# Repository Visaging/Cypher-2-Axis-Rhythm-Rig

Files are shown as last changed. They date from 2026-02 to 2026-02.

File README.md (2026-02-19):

# Cypher - 2 Axis Rhythm Rig
# TBA






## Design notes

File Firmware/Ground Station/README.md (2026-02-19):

# Breakdown Of the Firmware
- I wrote a custom protocol that sends a 13-byte package to the FC in the same format as designed in the firmware for the FC.
	- Joystick Axis: `Throttle`, `Yaw`, `Pitch`, `Roll`
	- Knobs: Direct Control for Gimbal Pitch and Roll
	- Buttons: Sends `CAM UP`, `CAM DOWN`, `ARM` and `DISARM` in a bitmask byte.
- I did not want to complicate things by getting the telemetry back from the drone itself instead, it sends the telemetry to the Raspberry Pi via `UART5`. The Raspberry Pi streams this telemetry back along with the video feed.
	- The ground station itself is set to blind transmission for now.
- Instead of displaying `BATTERY: 3.5V` on the OLED, I added some basic maths to map the voltage into a clean percentage based system. Now the OLED displays `BATTERY: 78%`.
- Although the UI for the OLED is pretty basic, it displays:
	- Battery percentage on the top.
	- Drone arm status: `ARMED`/`DISARMED` in the middle.
	- Raw stick values: `Throttle:`, `Roll:` and `Pitch:` on the bottom.

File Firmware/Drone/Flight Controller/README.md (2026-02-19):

# Breakdown:
- Since I'm using `DRV8313` as the motor drivers for the gimbal motors, I wrote a custom Sinusoidal PWM generator to drive the motors.
	- I also bumped the timer frequency to `20KHz` so the motors don't make a band of their own.
- Since I added a disarm button on the Ground Station, I added a safety mechanism to prevent accidental button presses and mid-air shutdowns unless absolutely necessary.
	- The drone disarms only when the button is pressed twice.
- Since I'm running a 6S battery structure for better efficiency and flight time, but my motors are rated for 4S batteries, I implemented a hardcoded firmware limit. It limits the motors to 66%.
	- This makes the drone work like it would when it's connected to a 4S battery structure.
- In the last firmware I wrote, I did not account for the buttons and knobs on the ground station. I expanded the 9-byte packet to a 13-byte package.
	- It now accommodates the knobs for direct control of the gimbal pitch and roll.
	- I added firmware for the buttons that handle `Camera Down`, `Camera Up`, `Arm`, and `Disarm`.
- I also did not set up the stabilisation for the gimbal in the last firmware. Now, the gimbal isn't just on manual control, it stabilises the camera.
	- I updated the math to subtract the drone's IMU angle from the target angle, resulting in active stabilisation even if the drone moves fast.

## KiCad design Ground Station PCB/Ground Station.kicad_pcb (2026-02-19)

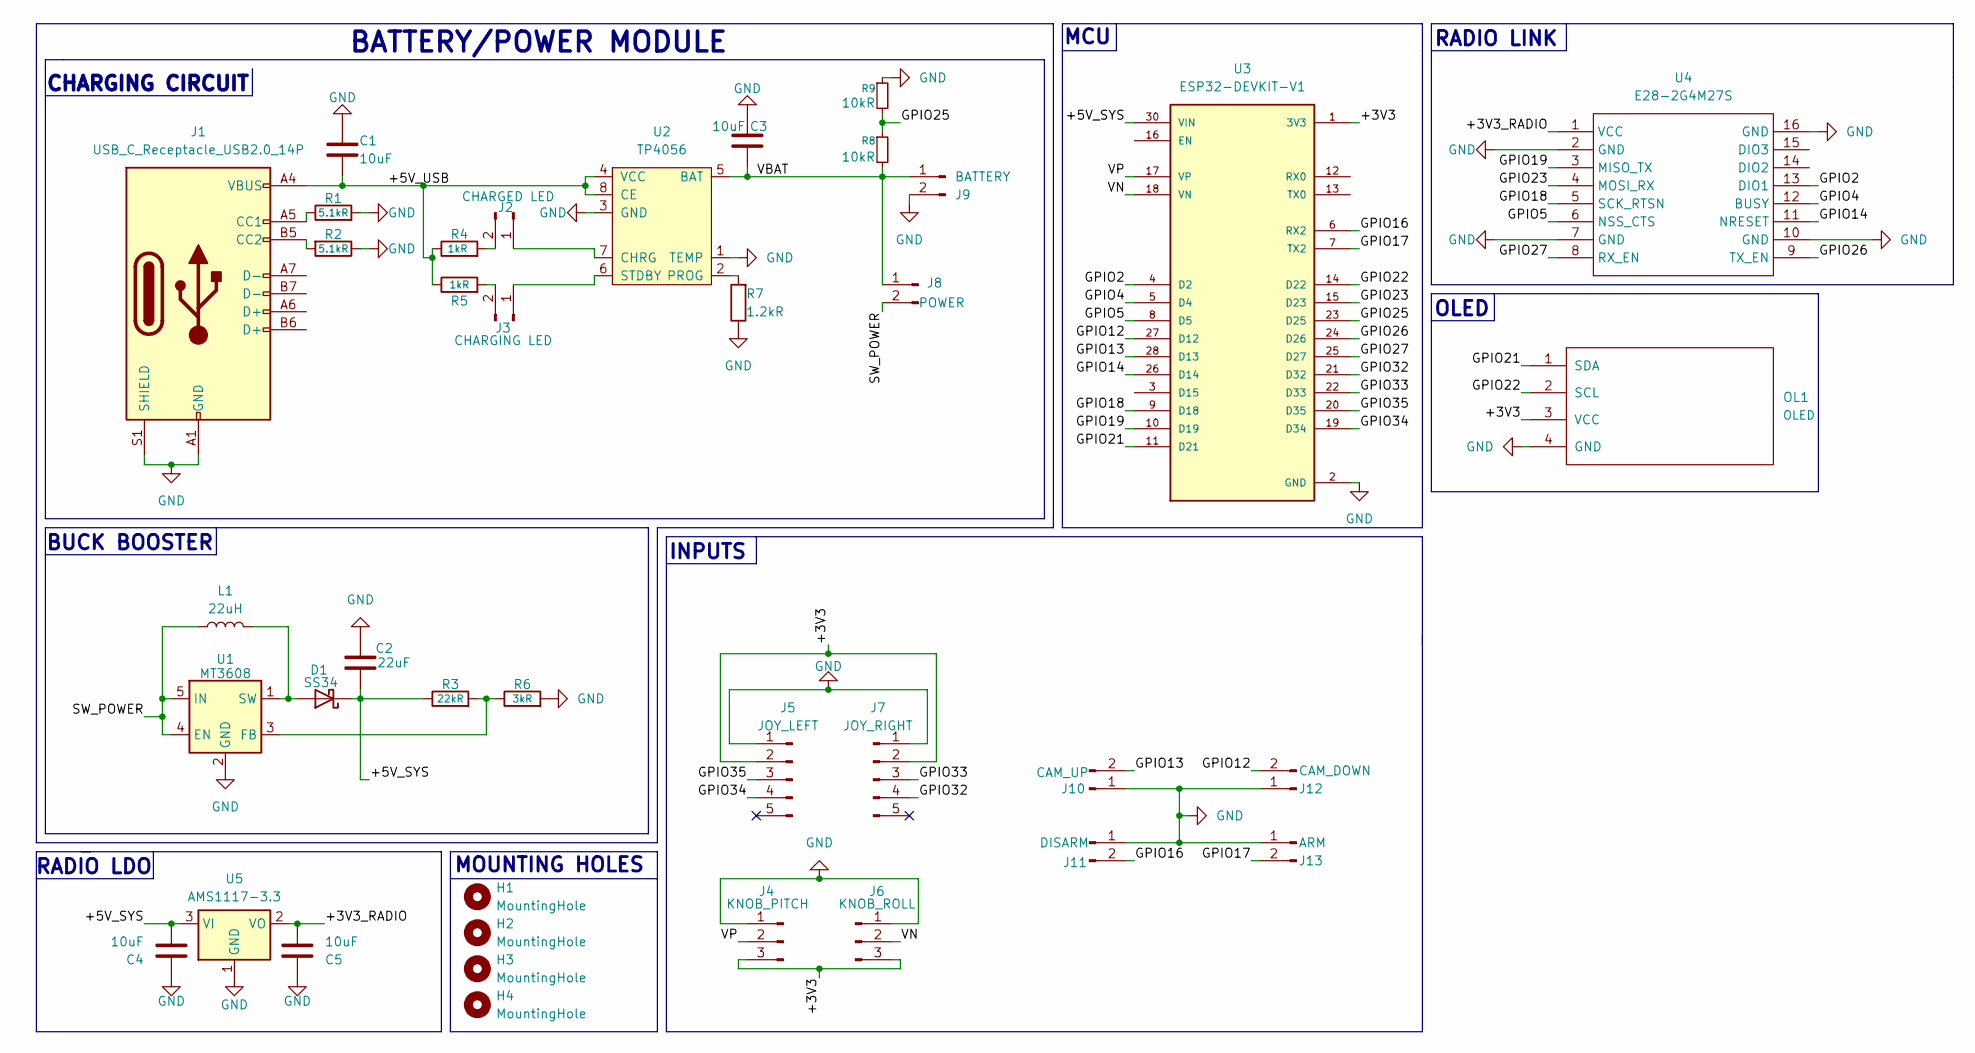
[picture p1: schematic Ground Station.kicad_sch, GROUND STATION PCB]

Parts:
C1, C4, C5: 10uF; C_0805_2012Metric
C2: 22uF; C_0805_2012Metric
C3: 10uF; CP_Radial_D5.0mm_P2.50mm
D1: SS34; D_SMA
H1, H2, H3, H4: MountingHole; MountingHole_3.2mm_M3
J1: USB_C_Receptacle_USB2.0_14P; USB_C_Receptacle_HRO_TYPE-C-31-M-12
J2: CHARGED LED; SolderWire-0.1sqmm_1x02_P3.6mm_D0.4mm_OD1mm
J3: CHARGING LED; SolderWire-0.1sqmm_1x02_P3.6mm_D0.4mm_OD1mm
J4: KNOB_PITCH; PinHeader_1x03_P2.54mm_Vertical
J5: JOY_LEFT; PinHeader_1x05_P2.54mm_Vertical
J6: KNOB_ROLL; PinHeader_1x03_P2.54mm_Vertical
J7: JOY_RIGHT; PinHeader_1x05_P2.54mm_Vertical
J8: POWER; PinHeader_1x02_P2.54mm_Vertical
J9: BATTERY; PinHeader_1x02_P2.54mm_Vertical
J10: CAM_UP; SolderWire-0.1sqmm_1x02_P3.6mm_D0.4mm_OD1mm
J11: DISARM; SolderWire-0.1sqmm_1x02_P3.6mm_D0.4mm_OD1mm
J12: CAM_DOWN; SolderWire-0.1sqmm_1x02_P3.6mm_D0.4mm_OD1mm
J13: ARM; SolderWire-0.1sqmm_1x02_P3.6mm_D0.4mm_OD1mm
L1: 22uH; L_Bourns-SRN6028
OL1: OLED; PinHeader_1x04_P2.54mm_Vertical
R1, R2: 5.1kR; R_0805_2012Metric
R3: 22kR; R_0805_2012Metric
R4, R5: 1kR; R_0805_2012Metric
R6: 3kR; R_0805_2012Metric
R7: 1.2kR; R_0805_2012Metric
R8, R9: 10kR; R_0805_2012Metric
U1: MT3608; SOP-8-1EP_4.57x4.57mm_P1.27mm_EP4.57x4.45mm
U2: TP4056; SOIC-8-1EP_3.9x4.9mm_P1.27mm_EP2.29x3mm; LCSC C16581
U3: ESP32-DEVKIT-V1; MODULE_ESP32_DEVKIT_V1; PARTREV N/A
U4: E28-2G4M27S; WIRELM-SMD_E28-2G4M2XS; Manufacturer Part E28-2G4M27S; LCSC Part Name E28-2G4M27S
U5: AMS1117-3.3; SOT-223-3_TabPin2

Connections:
/+3V3: J4.3, J5.2, J6.3, J7.2, OL1.3 (VCC), U3.1 (3V3)
/+3V3_RADIO: C5.2, U4.1 (VCC), U5.2 (VO)
/+5V_SYS: C2.2, C4.2, D1.1 (K), R3.1, U3.30 (VIN), U5.3 (VI)
/+5V_USB: C1.2, J1.A4 (VBUS), J1.A9 (VBUS), J1.B4 (VBUS), J1.B9 (VBUS), R4.1, R5.1, U2.4 (VCC), U2.8 (CE)
/GPIO2: U3.4 (D2), U4.13 (DIO1)
/GPIO4: U3.5 (D4), U4.12 (BUSY)
/GPIO5: U3.8 (D5), U4.6 (NSS_CTS)
/GPIO12: J12.2, U3.27 (D12)
/GPIO13: J10.2, U3.28 (D13)
/GPIO14: U3.26 (D14), U4.11 (NRESET)
/GPIO16: J11.2, U3.6 (RX2)
/GPIO17: J13.2, U3.7 (TX2)
/GPIO18: U3.9 (D18), U4.5 (SCK_RTSN)
/GPIO19: U3.10 (D19), U4.3 (MISO_TX)
/GPIO21: OL1.1 (SDA), U3.11 (D21)
/GPIO22: OL1.2 (SCL), U3.14 (D22)
/GPIO23: U3.15 (D23), U4.4 (MOSI_RX)
/GPIO25: R8.1, R9.2, U3.23 (D25)
/GPIO26: U3.24 (D26), U4.9 (TX_EN)
/GPIO27: U3.25 (D27), U4.8 (RX_EN)
/GPIO32: J7.4, U3.21 (D32)
/GPIO33: J7.3, U3.22 (D33)
/GPIO34: J5.4, U3.19 (D34)
/GPIO35: J5.3, U3.20 (D35)
/SW_POWER: J8.2, L1.1, U1.4 (EN), U1.5 (IN)
/VBAT: C3.2, J8.1, J9.1, R8.2, U2.5 (BAT)
/VN: J6.2, U3.18 (VN)
/VP: J4.2, U3.17 (VP)
GND: C1.1, C2.1, C3.1, C4.1, C5.1, J1.A1 (GND), J1.A12 (GND), J1.B1 (GND), J1.B12 (GND), J1.S1 (SHIELD), J4.1, J5.1, J6.1, J7.1, J9.2, J10.1, J11.1, J12.1, J13.1, OL1.4 (GND), R1.2, R2.1, R6.2, R7.1, R9.1, U1.2 (GND), U2.1 (TEMP), U2.3 (GND), U3.2 (GND), U3.29 (GND), U4.2 (GND), U4.7 (GND), U4.10 (GND), U4.16 (GND), U5.1 (GND)
unnamed: D1.2 (A), L1.2, U1.1 (SW)
unnamed: J1.A5 (CC1), R1.1
unnamed: J1.B5 (CC2), R2.2
unnamed: J2.1, U2.7 (CHRG)
unnamed: J2.2, R4.2
unnamed: J3.1, U2.6 (STDBY)
unnamed: J3.2, R5.2
unnamed: R3.2, R6.1, U1.3 (FB)
unnamed: R7.2, U2.2 (PROG)

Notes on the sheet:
MCU
OLED
INPUTS
CHARGING CIRCUIT
MOUNTING HOLES
RADIO LINK
BATTERY/POWER MODULE
BUCK BOOSTER
RADIO LDO

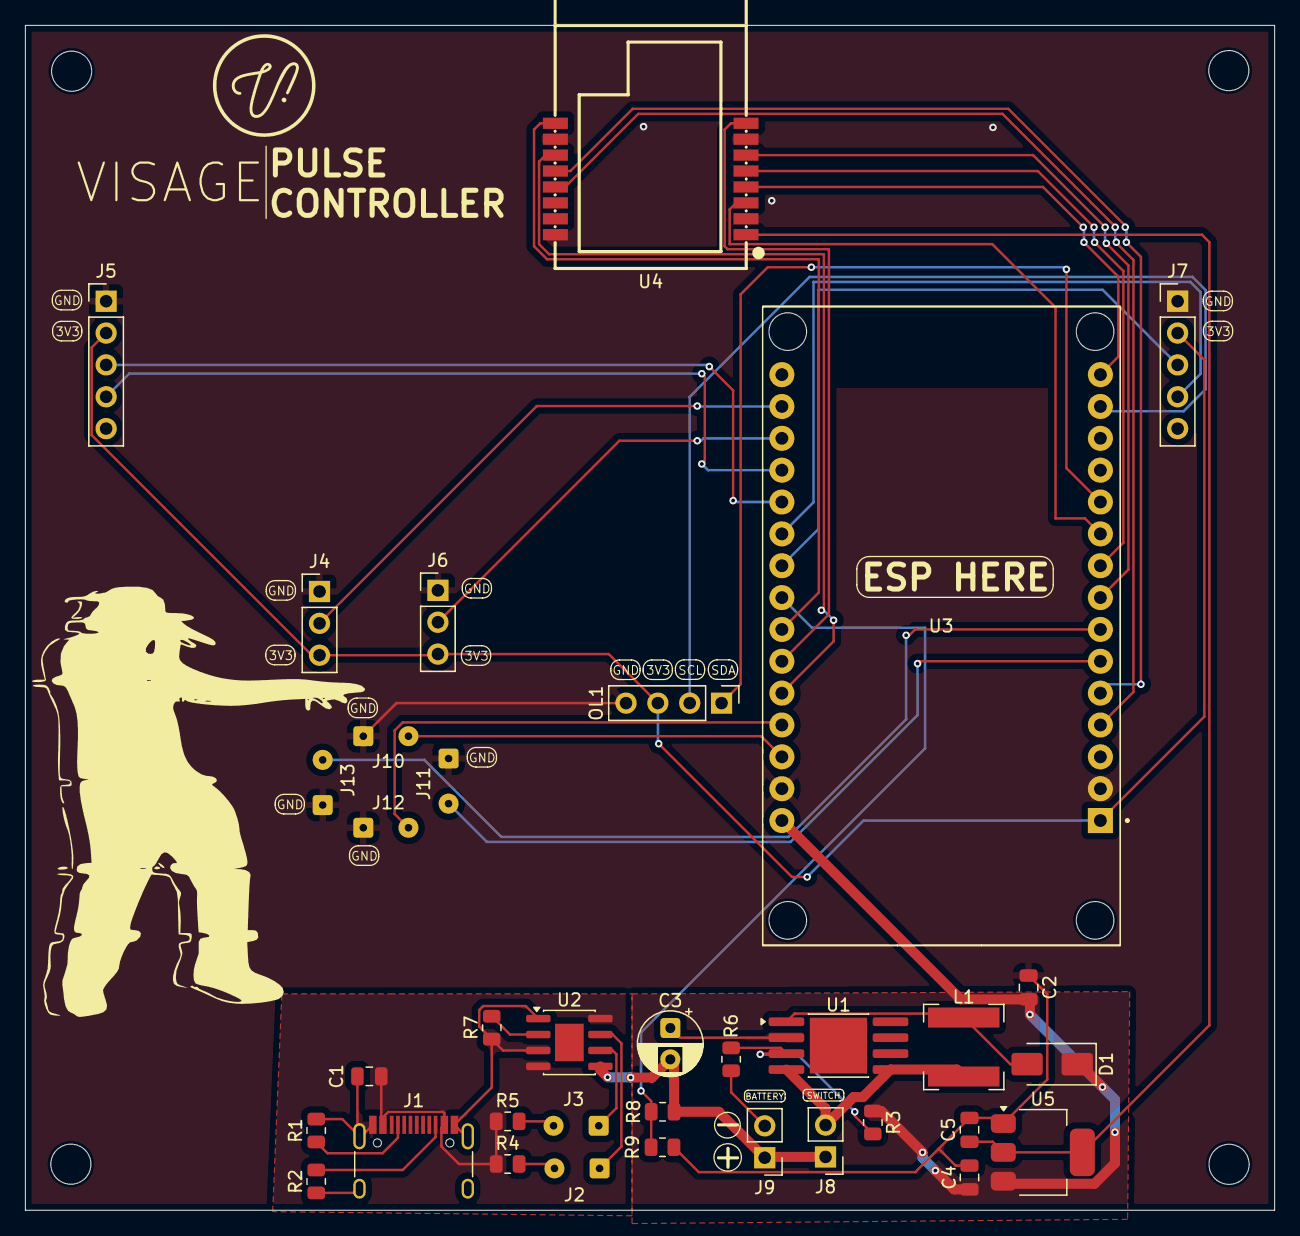
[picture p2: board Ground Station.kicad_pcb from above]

Board: 2 copper layers, 99.6 x 94.5 mm, 39 parts (0 on the bottom side), 38 nets.

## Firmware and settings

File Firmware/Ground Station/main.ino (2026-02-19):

#include <SPI.h>
#include <Wire.h>
#include <Adafruit_GFX.h>
#include <Adafruit_SSD1306.h>
#include <SX128XLT.h>

// ================================================================
// --- 1. PIN DEFINITIONS (MATCHING YOUR SCHEMATIC) ---
// ================================================================

// Analog Inputs (Joysticks + Knobs)
#define PIN_JOY_YAW     35
#define PIN_JOY_THR     34
#define PIN_JOY_ROLL    33
#define PIN_JOY_PITCH   32
#define PIN_KNOB_PITCH  36 // VP
#define PIN_KNOB_ROLL   39 // VN

// Digital Inputs (Buttons)
#define PIN_BTN_UP      13
#define PIN_BTN_DOWN    12
#define PIN_BTN_ARM     17
#define PIN_BTN_DISARM  16

// Radio (E28-2G4M27S / SX1280)
#define NSS_PIN         5
#define RST_PIN         14
#define BUSY_PIN        4
#define DIO1_PIN        2
#define RX_EN_PIN       27
#define TX_EN_PIN       26
// SPI (VSPI Default): MISO=19, MOSI=23, SCK=18

// Battery & OLED
#define PIN_BATTERY     25
#define SCREEN_WIDTH    128
#define SCREEN_HEIGHT   64
#define OLED_RESET      -1 

// ================================================================
// --- 2. CONFIGURATION & DATA STRUCTURES ---
// ================================================================

// Radio Settings (Must match Drone Receiver Settings)
#define LORA_FREQ       2400000000 // 2.4GHz
#define LORA_BW         LORA_BW_0400
#define LORA_SF         LORA_SF7
#define LORA_CR         LORA_CR_4_5
#define TX_POWER        12         // dBm

// Control Packet (13 Bytes - Sends TO Drone)
typedef struct __attribute__((packed)) {
    int16_t throttle;   // 1000 - 2000
    int16_t roll;       // 1000 - 2000
    int16_t pitch;      // 1000 - 2000
    int16_t yaw;        // 1000 - 2000
    int16_t knob_pitch; // 1000 - 2000
    int16_t knob_roll;  // 1000 - 2000
    uint8_t buttons;    // Bitmask
} RC_Input_t;

// Objects
SX128XLT LT;
Adafruit_SSD1306 display(SCREEN_WIDTH, SCREEN_HEIGHT, &Wire, OLED_RESET);
RC_Input_t packet;

// Globals
unsigned long last_tx_time = 0;
bool local_armed_state = false; // Tracks button presses for UI only

// ================================================================
// --- 3. SETUP ---
// ================================================================
void setup() {
    Serial.begin(115200);

    // 1. Init Pins
    pinMode(PIN_JOY_YAW, INPUT); pinMode(PIN_JOY_THR, INPUT);
    pinMode(PIN_JOY_ROLL, INPUT); pinMode(PIN_JOY_PITCH, INPUT);
    pinMode(PIN_KNOB_PITCH, INPUT); pinMode(PIN_KNOB_ROLL, INPUT);
    pinMode(PIN_BATTERY, INPUT);
    
    // Buttons (Internal Pullups active)
    pinMode(PIN_BTN_UP, INPUT_PULLUP);
    pinMode(PIN_BTN_DOWN, INPUT_PULLUP);
    pinMode(PIN_BTN_ARM, INPUT_PULLUP);
    pinMode(PIN_BTN_DISARM, INPUT_PULLUP);

    // 2. Init OLED
    if(!display.begin(SSD1306_SWITCHCAPVCC, 0x3C)) { 
        Serial.println(F("OLED Failed")); for(;;);
    }
    display.clearDisplay();
    display.setTextColor(SSD1306_WHITE);
    display.setCursor(10, 20);
    display.setTextSize(2);
    display.println("VISAGE | PULSE");
    display.setTextSize(1);
    display.setCursor(30, 45);
    display.println("SYSTEM INITIALISING...");
    display.display();

    // 3. Init Radio
    SPI.begin();
    if (LT.begin(NSS_PIN, RST_PIN, 0, DIO1_PIN, BUSY_PIN)) {
        Serial.println(F("SX1280 Found"));
        LT.setupLoRa(LORA_FREQ, 0, LORA_SF, LORA_BW, LORA_CR); 
    } else {
        Serial.println(F("SX1280 Error"));
        display.clearDisplay();
        display.setCursor(0,0);
        display.println("RADIO ERROR");
        display.display();
        while(1);
    }
    
    // Config RX/TX Switching Pins (E28 specific)
    LT.setRXENPin(RX_EN_PIN);
    LT.setTXENPin(TX_EN_PIN);
}

// ================================================================
// --- 4. HELPER FUNCTIONS ---
// ================================================================

// Map ADC (0-4095) to RC (1000-2000)
int16_t readChannel(int pin, bool invert) {
    int raw = analogRead(pin);
    int16_t val = map(raw, 0, 4095, 1000, 2000);
    if(val < 1000) val = 1000;
    if(val > 2000) val = 2000;
    return invert ? (3000 - val) : val;
}

void drawDashboard() {
    display.clearDisplay();

    // --- TOP BAR (Local Battery %) ---
    // 1. Read Voltage
    // ADC 4095 = 3.3V Pin Voltage. 
    // Divider is 10k/10k (Divide by 2), so Battery Voltage = Pin Voltage * 2
    float gs_volt = (analogRead(PIN_BATTERY) / 4095.0) * 3.3 * 2.0;
    
    // 2. Convert to Percentage (Linear mapping for 1S LiPo: 3.3V to 4.2V)
    int bat_pct = (int) ((gs_volt - 3.3) / (4.2 - 3.3) * 100.0);
    
    // 3. Constrain to 0-100%
    if(bat_pct > 100) bat_pct = 100;
    if(bat_pct < 0) bat_pct = 0;
    
    display.setTextSize(1);
    display.setCursor(0,0);
    display.print("BATTERY: "); display.print(bat_pct); display.print("%");

    // --- CENTER (Arm Status) ---
    display.setCursor(35, 20);
    display.setTextSize(2);
    if(local_armed_state) {
        display.print("ARMED");
    } else {
        display.print("DISARMED");
    }

    // --- BOTTOM (Stick Debug) ---
    display.setTextSize(1);
    display.setCursor(0, 50);
    display.print("Throttle:"); display.print(packet.throttle);
    display.print(" Roll:"); display.print(packet.roll);
    display.print(" Pitch:"); display.print(packet.pitch);
    
    display.display();
}

// ================================================================
// --- 5. MAIN LOOP ---
// ================================================================
void loop() {
    // 1. READ INPUTS
    // Note: Change 'false' to 'true' if any stick is reversed
    packet.yaw        = readChannel(PIN_JOY_YAW, false);
    packet.throttle   = readChannel(PIN_JOY_THR, false); 
    packet.roll       = readChannel(PIN_JOY_ROLL, false);
    packet.pitch      = readChannel(PIN_JOY_PITCH, false);
    packet.knob_pitch = readChannel(PIN_KNOB_PITCH, false);
    packet.knob_roll  = readChannel(PIN_KNOB_ROLL, false);

    // Read Buttons (Active LOW -> Set Bit High)
    packet.buttons = 0;
    if(digitalRead(PIN_BTN_UP) == LOW)     packet.buttons |= 0x01;
    if(digitalRead(PIN_BTN_DOWN) == LOW)   packet.buttons |= 0x02;
    if(digitalRead(PIN_BTN_ARM) == LOW)    packet.buttons |= 0x04;
    if(digitalRead(PIN_BTN_DISARM) == LOW) packet.buttons |= 0x08;

    // Update Local Status for Display
    if(packet.buttons & 0x04) local_armed_state = true;
    if(packet.buttons & 0x08) local_armed_state = false;

    // 2. TRANSMIT CYCLE (50Hz - every 20ms)
    if (millis() - last_tx_time > 20) {
        // Send packet blindly (No ACK required)
        LT.transmit((uint8_t*)&packet, sizeof(packet), 0, TX_POWER, WAIT_TX);
        last_tx_time = millis();
    }

    // 3. UPDATE DISPLAY (10Hz)
    static unsigned long last_ui_time = 0;
    if (millis() - last_ui_time > 100) {
        drawDashboard();
        last_ui_time = millis();
    }
}
